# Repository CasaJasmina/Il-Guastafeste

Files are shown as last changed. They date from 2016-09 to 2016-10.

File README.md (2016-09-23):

# Il-Guastafeste
Il guastafeste repository 

Il Guastafeste is a Party/Sound Silencer System that interacts directly with your home’s audio stereo devices and lights. 
The system is able to detect the noise present in the house, if the sound is too noisy after 23 O’Clock, 
Il Guastafeste gives the user two chances to turn down the music volume and save the relationship with the neighbours. 
If not, il Guastafeste will shut down the music and dim down the lights, breaking the party.

Il Guastafeste will be exhibited at Maker Faire Home 2016 in Rome and will be a permanent home smart living object at 
Casa Jasmina in Turin.

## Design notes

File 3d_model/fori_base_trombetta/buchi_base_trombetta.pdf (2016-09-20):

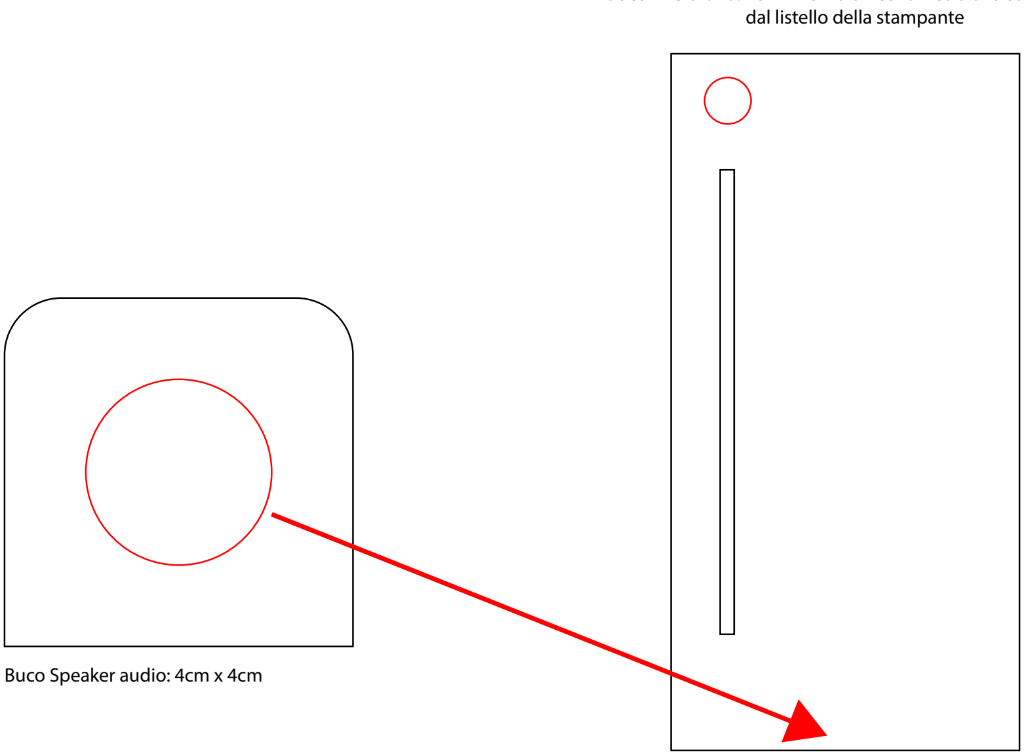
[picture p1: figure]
Buco Speaker audio: 4cm x 4cm; dal listello della stampante

Buco microfono: 1cm x 1cm a un centimetro di distanza

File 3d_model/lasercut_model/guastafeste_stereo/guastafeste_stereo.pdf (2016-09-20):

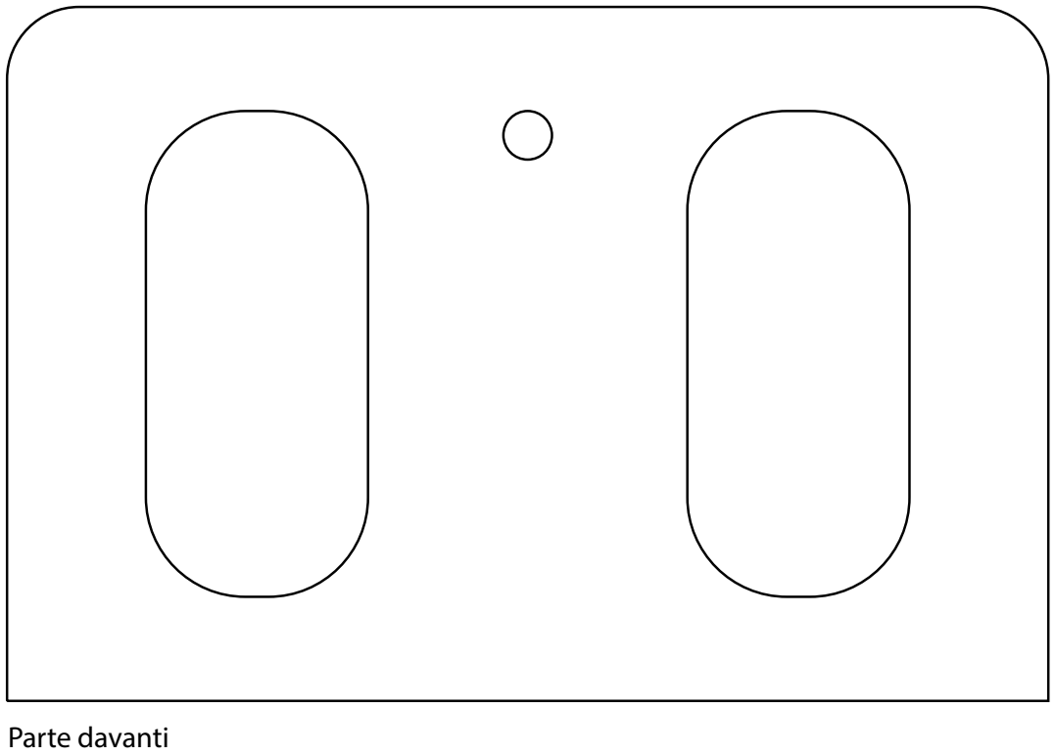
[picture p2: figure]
Parte davanti

Buchi speaker: 3,2 cm larghezza x 7 cm lunghezza buco potenziometro: 0,7 cm x 0,7 cm

Parte dietro
Buco 9V: 0,5 cm x 0,5 cm
Buco ipod/jack: 0,5 cm x 0,5 cm

Dimensioni totali: 15x10x5 (Profondità/lunghezza dei lati: 5 cm).

Purtroppo i lati non riesco a farli in Rhino per via dei bordi arrotondati superiori, bisognerebbe intagliarli con il pattern a zig zag che mi avevi fatto vedere
(in modo da essere essibili e quindi arrotondabili).

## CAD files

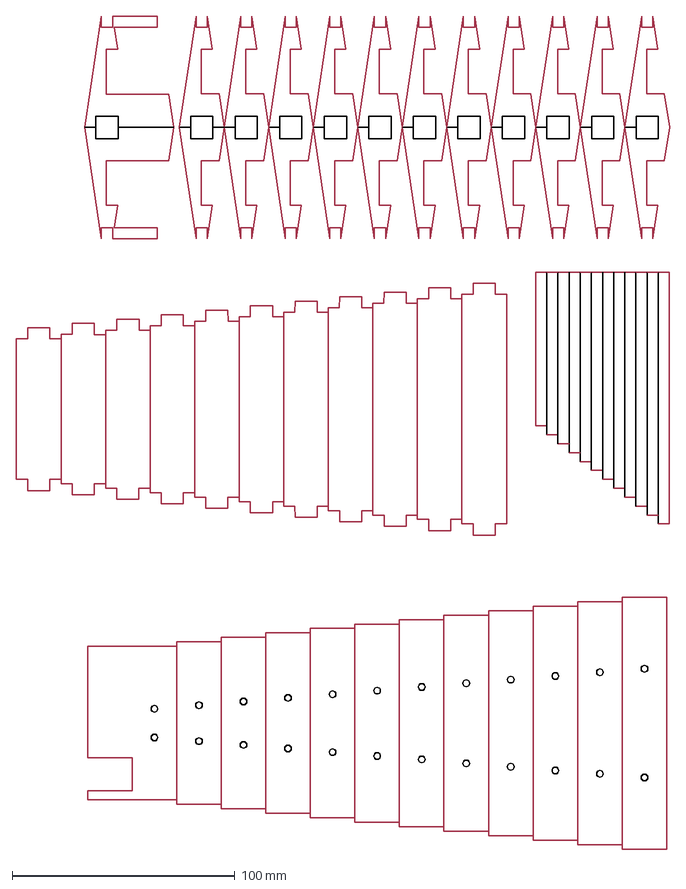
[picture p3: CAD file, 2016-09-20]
3d_model/lasercut_model/guastafeste_trombetta/gustafeste_trombetta_final_14_44.dxf
293.2 x 374.0 mm

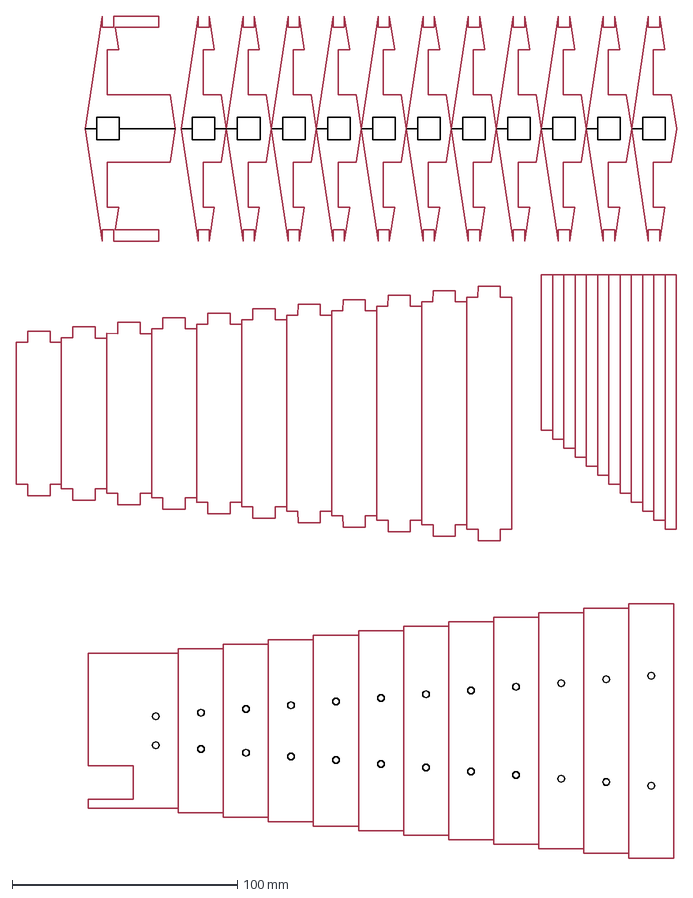
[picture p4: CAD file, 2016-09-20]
3d_model/lasercut_model/guastafeste_trombetta/gustafeste_trombetta_final_14_32.dxf
293.2 x 374.0 mm

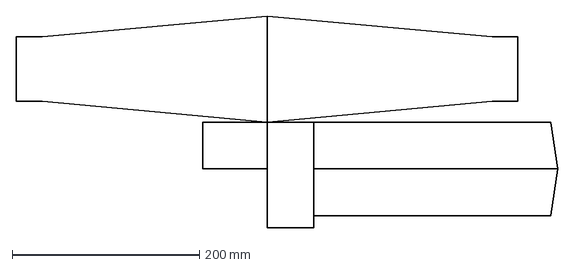
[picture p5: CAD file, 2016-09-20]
3d_model/lasercut_model/guastafeste_trombetta/guastafeste_lycra_15_02.dxf
577.5 x 226.0 mm

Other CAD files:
3d_model/3d_printing_model/luce_trombetta/base_luce.3dm
3d_model/3d_printing_model/parte_gialla_trombetta/YellowIvanSeal.3dm
3d_model/3d_printing_model/rocchetto_trombetta/rocchetto_servo_trombetta.3dm
3d_model/3d_printing_model/trace_il_guastafeste/trace_guastafeste.3dm
3d_model/lasercut_model/guastafeste_stereo/guastafeste_stereo_final.3dm
3d_model/lasercut_model/guastafeste_trombetta/ilguastafeste_lingua.3dm

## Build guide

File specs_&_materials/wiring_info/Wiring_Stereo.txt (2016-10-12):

Amplifier
VDD -> 5v
GND -> GND
L+ -> dac0
L- -> GND
G0 -> 5
G1 -> 4
SR -> 3
SL -> 2

Potentiometer
A -> A1
GND -> GND
5v -> 5v

Jack
right -> R+
left -> L+

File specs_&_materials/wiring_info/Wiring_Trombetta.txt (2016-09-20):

Amplifier
VDD -> 5v
GND -> GND
L+ -> dac0
L- -> GND
G0 -> 2
G1 -> 3

Micro-SD

3v -> VCC
GND -> GND
SCLK -> 9
DO -> 10
DI -> 8
CS -> 4

Microphone
DO -> A1
+ -> 5v
G -> GND

Thermal Printer
GND -> GND
RX -> 14
5v -> 5v

Servo
GND -> GND
5v -> 5v
D -> 5

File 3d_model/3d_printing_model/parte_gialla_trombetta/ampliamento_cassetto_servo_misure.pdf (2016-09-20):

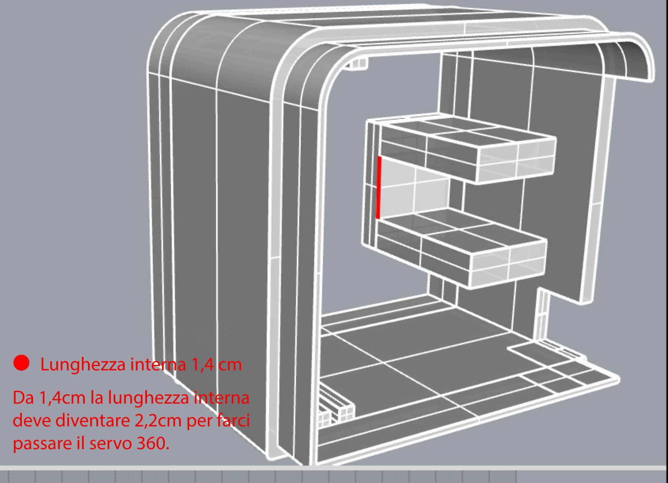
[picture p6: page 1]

䰀甀渀最栀攀稀稀愀椀渀琀攀爀渀愀㄀Ⰰ㐀挀洀
䐀愀㄀Ⰰ㐀挀洀氀愀氀甀渀最栀攀稀稀愀椀渀琀攀爀渀愀
搀攀瘀攀搀椀瘀攀渀琀愀爀攀㈀Ⰰ㈀挀洀瀀攀爀昀愀爀挀椀 瀀愀猀猀愀爀攀椀氀猀攀爀瘀漀㌀㘀　⸀

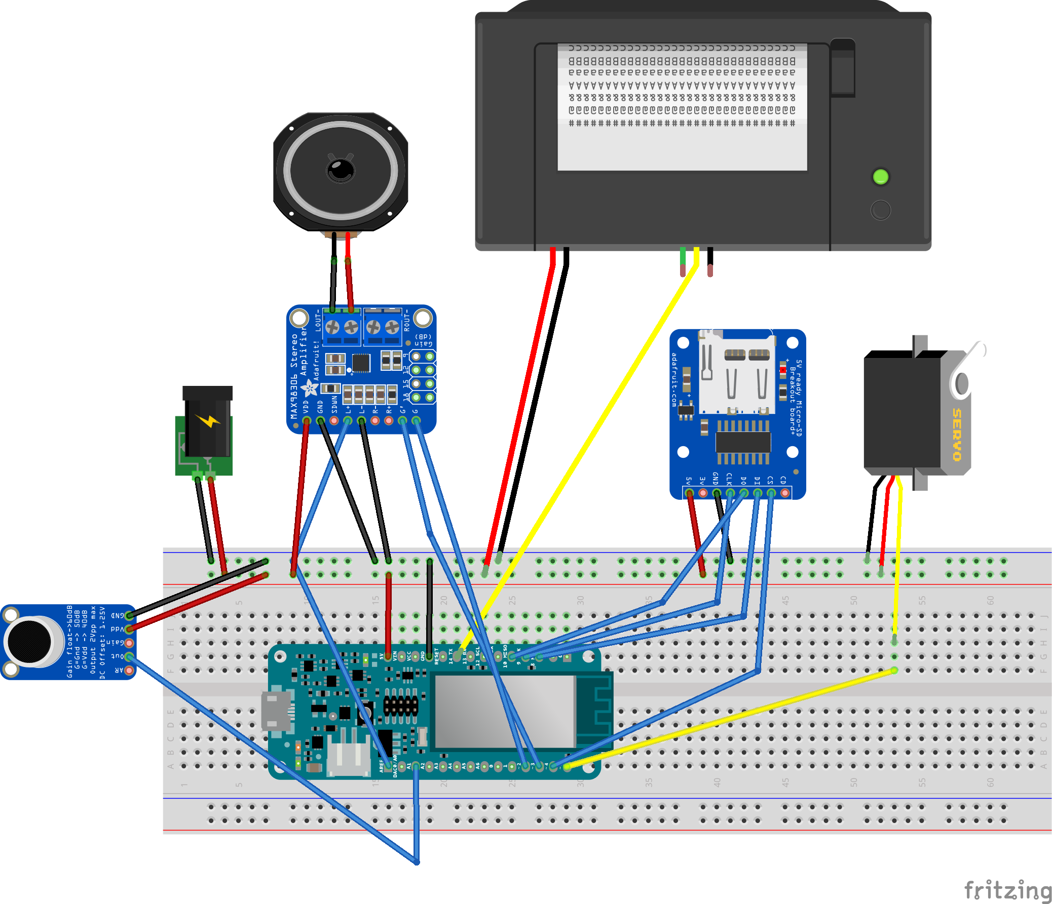
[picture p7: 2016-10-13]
specs_&_materials/wiring_info/fritzing/il_guastafeste_trombetta.png

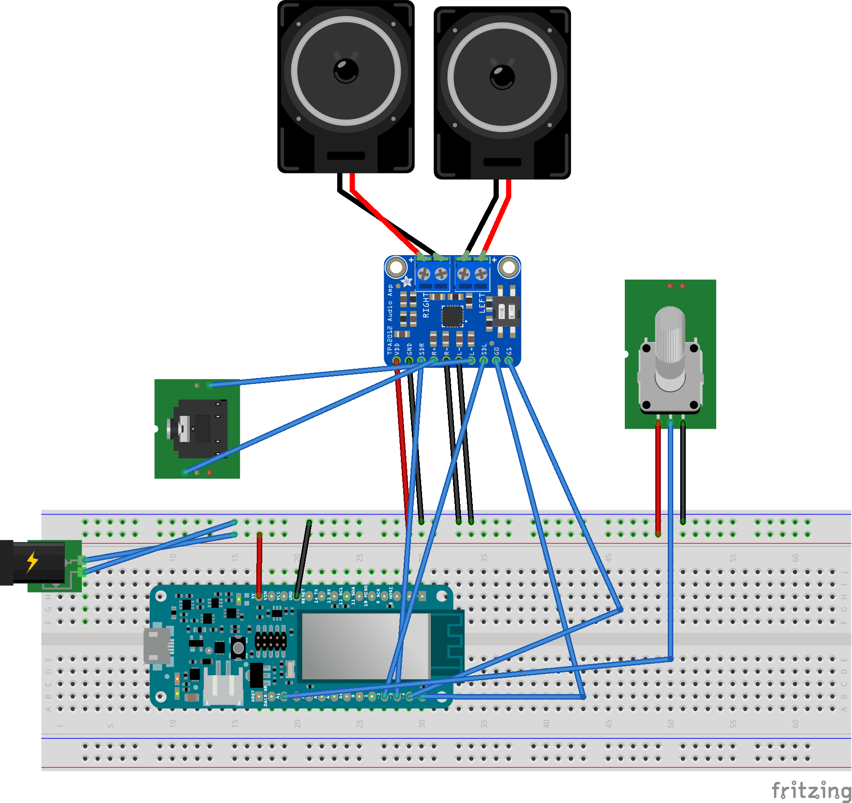
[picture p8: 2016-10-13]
specs_&_materials/wiring_info/fritzing/il_guastafeste_stereo.png

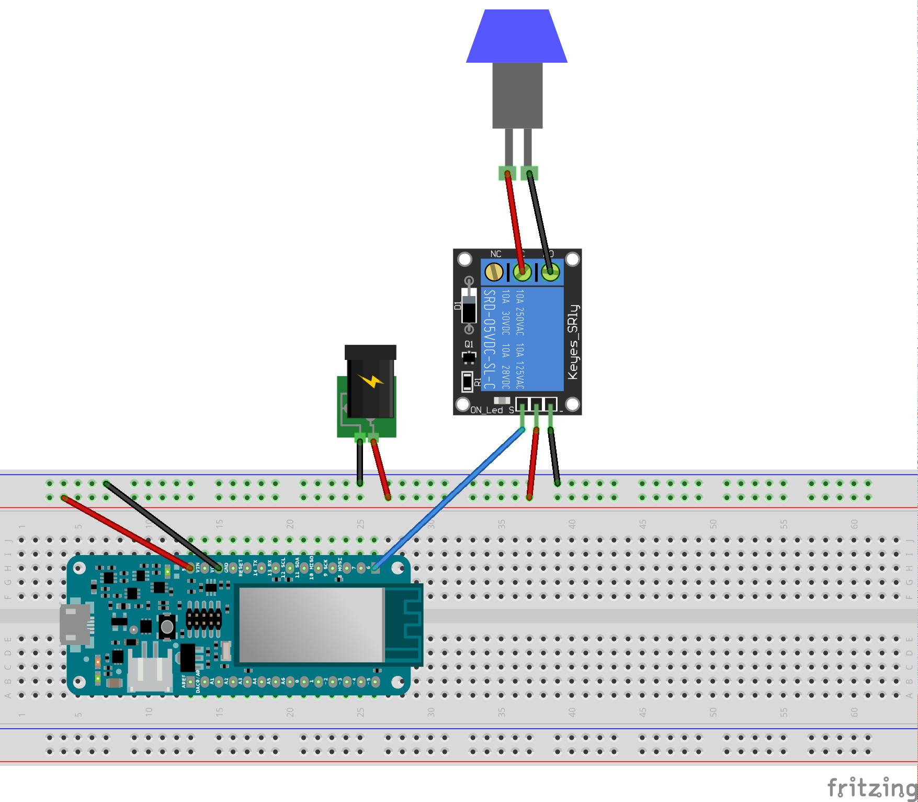
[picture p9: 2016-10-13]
specs_&_materials/wiring_info/fritzing/il_guastafeste_light.png

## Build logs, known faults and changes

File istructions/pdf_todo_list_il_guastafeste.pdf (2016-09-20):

## Todo List il Guastafeste

Design Stereo:

- Allo stereo manca ancora un case, che io farei in legno. Ho disegnato il case in Rhino e l’ho estruso, tuttavia non sono riuscito a fare le pareti dato che la parte superiore del Case è arrotondata e non so come si fa il pattern a zig-zag per rendere flessibile i bordi. Ti prego di dare una controllata al file prima di esportarlo in .dxf . Il File lo trovi qui:

3d_model -> lasercut_model -> guastafeste_stereo

Nel link troverai un pdf con le lunghezze e larghezza, cosi come il file .3dm fatto da me.

Design Trombetta:

- Purtroppo nella trombetta dobbiamo ristampare la parte gialla che aveva fatto Tommaso, dato che ora utilizzo un Servo 360 (è più grande del Servo normale). Tuttavia, l’unica cosa da cambiare è solo la grandezza del “cassettino” del servo. Anche qui, tutte le info (Grandezze e pezzo da ridimensionare le trovi nel seguente link:

3d_model -> 3d_printing_model -> parte_gialla_trombetta

- Per il Servo 360, ho progettato anche un rocchetto come testa del motore del servo, che servirà a far arrotolare e bloccare (nei due buchi) il filo di nylon che gestisce il “naso” della trombetta. Se dovesse essere troppo dispendioso stampare il pezzo, puoi incollare il rocchetto di plastica che ti ho inviato sulla parte plastica alla testa del motore, facendo attenzione a tenere in alto la parte con il buco (servirà a tenere fermi le due estremità del filo di nylon).

3d_model -> 3d_printing_model -> rocchetto_trombetta
(le grandezze le trovi insieme al model nel file .3dm)

I due buchi servono per l’appunto a bloccare il filo, con un bel nodino, una volta che la parte superiore è srotolata del tutto.

- Nella parte bianca, dove verranno installati lo speaker, la Thermal Printer e il microfono, mancano ancora i buchi per lo Speaker e per il microfono. Tommaso voleva farli con il Dremel. Nel link sottostante trovi le grandezze e la posizione in cui dovranno essere fatti i buchi.

3d_model -> fori_base_trombetta

Design Luce:

- Per la luce bisogna ancora fare la parte di decoro, onestamente non ho fatto praticamente nulla a riguardo, dato che la luce, il relay e l’arduino annesso l’ho lasciato a Torino. Qui ti puoi sbizzarrire te, per me è uguale quale tipo design abbia la lampada, fai che ti riesce più veloce. Purtroppo non ho alcuna misura, sia del bulbo che della parte superiore della lampada

Programmazione Servo Trombetta:

Una volta collegato il Servo alla parte superiore della Trombetta (Arrotolando il Nylon nel rocchetto e fissandolo fuori facendolo passare dai buchi), potrai testare la velocità e forza del Servo. Nel caso in cui il Servo non fosse in grado di alzare tutta la parte, puoi sempre modificare il codice, aumentando la velocità.

Le linee di codice da modificare sono le seguenti:

Linea 176 -> servoMotor(true,500,20);
Linea 230 -> servoMotor(true,500,20);
Linea 253 -> servoMotor(false,500,20);
Linea 285 -> servoMotor(true,500,20);
Linea 316 -> servoMotor(false,1000,20);
Linea 339 -> servoMotor(false,1500,20);

In tutte queste linee dovrai sostituire l’ultimo parametro della funzione servoMotor (ovvero il 20), con il numero 40 o 60, in base alla quantità di velocità che necessita il Servo.

Il file lo trovi qui:

final_sketches -> _2016_09_08_ilguastafeste_trombetta -> _2016_09_08_ilguastafeste_trombetta.ino

Altro:

Per la Maker Faire avrei bisogno anche di un rullino di carta nuovo per la Thermal Printer e di una batteria LiPo Battery o caricatore Usb (con la presa per la corrente elettrica) per l’arduino che gestisce la luce.

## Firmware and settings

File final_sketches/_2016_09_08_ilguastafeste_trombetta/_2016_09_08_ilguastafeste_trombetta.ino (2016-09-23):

/*
 *  8 September 2016
 *  Il Guastafeste - Trombetta
 *  Ivan Iovine
 *  
 *  Casa Jasmina / Maker Faire Rome
 *
 */

 
#include <Servo.h>
//Include Libraries for WLAN and MQTT Communication
#include <WiFi101.h>
#include <WiFiUdp.h>
#include <ArduinoCloud.h>

// Library for Thermal Printer
#include "Adafruit_Thermal.h"

// Libraries for Audio File
#include <SPI.h>
#include <SD.h>
#include <AudioZero.h>

//Libraries for Hours - RTC
#include <RTCZero.h>

// build a wifi object
WiFiSSLClient sslClient;

// build a RTCZero object
RTCZero rtc;

// build a UDP Connection object
WiFiUDP Udp;

// build a new object "ilguastafestetrombetta"
ArduinoCloudThing ilguastafestetrombetta;

// Servo object
Servo servoguastafeste;  // create servo object to control a servo


Adafruit_Thermal printer(&Serial1);
#define TX_PIN 1 // Arduino transmit  PIN 14
#define RX_PIN 0 // Arduino receive

// Variables for WLAN Communication
char *ssid = "";
char *pass = "";

// Arduino Cloud settings and credentials
const char userName[]   = "dummknopf";
const char thingName[] = "ilguastafestetrombetta";
const char thingId[]   = "c8f20740-561f-4991-ba06-c0cc8ed349b1";
const char thingPsw[]  = "687e8869-815f-4d25-965d-b166b6a9b0da";

// UDP setup
unsigned int localPort = 2390;      // local port to listen for UDP packets
IPAddress timeServer(129, 6, 15, 28); // time.nist.gov NTP server
const int NTP_PACKET_SIZE = 48; // NTP time stamp is in the first 48 bytes of the message
byte packetBuffer[ NTP_PACKET_SIZE]; //buffer to hold incoming and outgoing packets
const int GMT = 2; //change this to adapt it to your time zone   hours*minutes*seconds

// Set Il Guastafeste Alarm
int hours = 13;
int minutes = 0;
int seconds = 0;
boolean after = false; // Check if time is after 23 hours


// Messages to Print
boolean message = false; // Check if it's time to print the message
String stepOne = "It's too Loud, please be Quiet!";
String stepTwo = "This is the last Warning!";
String stepThree = "The Party is over, Good Night!"; 

// twelve servo objects can be created on most boards
int pos = 90;    // variable to store the servo position
boolean stop_servo = true;

// millis variables for average noise value
unsigned long previousMillis = 0; 
unsigned long currentMillis;
const long interval = 30000;

// Variables for the Microphone
float totValue;
float loudValue;
unsigned int sample;
int peakRaw;
int countLoud = 0;



void setup() {
  
  Serial.begin (9600); 

  // attempt to connect to WiFi network:
  //Serial.print("Attempting to connect to WPA SSID: ");
  //Serial.println(ssid);
  
  // Check if the MKR1000 is connected on WIFI
  if(WiFi.begin(ssid, pass) != WL_CONNECTED) {
    // unsuccessful, retry in 4 seconds
    Serial.print("failed ... ");
    delay(4000);
    Serial.print("retrying ... ");
  }
  else
  {
    //
  }
    //Begin Printer Serial
    Serial1.begin(9600);
    
    //Begin Printer Library
    printer.begin(250);

    //Begin Time the libraries and Functions
    rtc.begin();
    GetCurrentTime();

    // Begin MQTT Communication
    ilguastafestetrombetta.begin(thingName, userName, thingId, thingPsw, sslClient);
    ilguastafestetrombetta.enableDebug();
    
    // define the properties
    ilguastafestetrombetta.addProperty("ilguastafestemaster", CHARSTRING, RW);
    ilguastafestetrombetta.addExternalProperty("ilguastafestestereo","ilguastafestestereoslave",CHARSTRING);
    
     if(!SD.begin(4)) {
      Serial.println("failed!");
     }
     else
     {
      Serial.println("Valid SD Card");
     }

       // Init Servo
    //servoguastafeste.attach(5);  // attaches the servo on pin 5 to the servo object


  
}

void loop() {
  
  currentMillis = millis();
  peakRaw = peak();
    
  ilguastafestetrombetta.poll();
  
    switch (countLoud) {
      case 0:
        
      totValue += peakRaw;
      if (currentMillis - previousMillis >= interval) 
      {
        previousMillis = currentMillis;
        Serial.println(totValue);
        Serial.println(interval);
        loudValue = (interval/totValue)*1000;
        Serial.println(loudValue);
    
        if(loudValue <= 500 && loudValue >= 1)
        {
            // Turn Down Stereo Volume
            ilguastafestetrombetta.writeProperty("ilguastafestemaster", "loud");
            
            // Change here the proprietes to manipulate the servo
            stop_servo = false; 
            if(stop_servo == false)
            {
              servoMotor(true,500,20);
              stop_servo = true;
            }
    
            message = true;
            
            if(message == true)
            {
              // Print the message
              printMessage(stepOne);
              Serial.println("Print Message!");
              message = false;
            }

            countLoud = 1;     
        }
        else
        {
          // Change here the proprietes to manipulate the servo
          stop_servo = false; 
          if(stop_servo == false)
          {
            servoMotor(false,500,0);
            stop_servo = true;
          }
          restart();
          Serial.println("COUNTLOUD 0");
       
        }
          totValue = 0; 
      }
      
      break;
      case 1:

      totValue += peakRaw;
      if (currentMillis - previousMillis >= interval) 
      {
        previousMillis = currentMillis;
        Serial.println(totValue);
        Serial.println(interval);
        loudValue = (interval/totValue)*1000;
        Serial.println(loudValue);
        
        if(loudValue <= 500 && loudValue >= 1)
        {
        
            // Turn Down Stereo Volume
             ilguastafestetrombetta.writeProperty("ilguastafestemaster", "tooloud");
             
             // Change here the proprietes to manipulate the servo
            stop_servo = false; 
            if(stop_servo == false)
            {
              servoMotor(true,500,20);
              stop_servo = true;
            }
    
             message = true;
            
            if(message == true)
            {
               // Print the message
               printMessage(stepTwo);
               Serial.println("Print Message!");
               message = false;
            } 

            countLoud = 2;
        }
        else
        {
          
          // Change here the proprietes to manipulate the servo
          stop_servo = false; 
          if(stop_servo == false)
          {
            servoMotor(false,500,20);
            stop_servo = true;
          }
          restart();
          Serial.println("COUNTLOUD 0");
  
        }
          totValue = 0;
      }
           
      break;
      case 2:

      totValue += peakRaw;
      if (currentMillis - previousMillis >= interval) 
      {
        previousMillis = currentMillis;
        Serial.println(totValue);
        Serial.println(interval);
        loudValue = (interval/totValue)*1000;
        Serial.println(loudValue);
        
        if(loudValue <= 500 && loudValue >= 1)
        {

            // Turn Out Lights and Stereo
            ilguastafestetrombetta.writeProperty("ilguastafestemaster", "partyisover");

            stop_servo = false; 
            if(stop_servo == false)
            {
              // Change here the proprietes to manipulate the servo
              servoMotor(true,500,20);
              stop_servo = true;
            }
                      
            message = true;
            
            if(message == true)
            {
              // Print the message
              printMessage(stepThree);
              Serial.println("Print Message!");
              message = false;
            }
            delay(2000);
            //Set Volume Speaker
            digitalWrite(1, HIGH);
            digitalWrite(2, LOW);
            digitalWrite(3, LOW);
            //Play the final sound
            finalAudio();
    
            // Restart the Sketch!
            countLoud = 3;
        }
        else
        {
          
          // Change here the proprietes to manipulate the servo
          stop_servo = false; 
          if(stop_servo == false)
          {
            servoMotor(false,1000,20);
            stop_servo = true;
          }
          restart();
          Serial.println("COUNTLOUD 0");
          
        }
          
          totValue = 0; 
        
        }
        
      break;
      case 3:

      totValue += peakRaw;
      if (currentMillis - previousMillis >= interval) 
      {
              delay(26000);
              // Change here the proprietes to manipulate the servo
              stop_servo = false; 
              if(stop_servo == false)
              {
                servoMotor(false,1500,20);
                stop_servo = true;
              }
              restart();
      }
      
      break;
      default:
        // Nothing happens here
      break;
    }
  }


//Printer Function
void printMessage(String stepMessage)
{
  
  printer.setSize('S');
  printer.justify('C');
  printer.println(stepMessage);
  printer.feed(5);
}

// Audio Speaker Function
void finalAudio()
{
   AudioZero.begin(44100);
   File audioFile = SD.open("tt.wav"); // open wave file from sdcard
    if (!audioFile) {
      Serial.println("error opening tt.wav");
    }
    AudioZero.play(audioFile);
    AudioZero.end();
}

// Take Raw Data every 50 ms from Microphone
int peak()
{
    unsigned long startMillis= millis();  // Start of sample window
    int peakToPeak = 0;   // peak-to-peak level
     
    unsigned int signalMax = 0;
    unsigned int signalMin = 1024;

     
       // collect data for 50 mS
       while (millis() - startMillis < 50)
       {
          sample = analogRead(A1);
          //Serial.println(sample);
          if (sample < 1024)  // toss out spurious readings
          {
             if (sample > signalMax)
             {
                signalMax = sample;  // save just the max levels
             }
             else if (sample < signalMin)
             {
                signalMin = sample;  // save just the min levels
             }
          }
       }
       peakToPeak = signalMax - signalMin;  // max - min = peak-peak amplitude
       return peakToPeak;
       Serial.println(peakToPeak);
       delay(500);
}

void restart()
{

     //Restart State
     ilguastafestetrombetta.writeProperty("ilguastafestemaster", "restart");
     delay(2000);
     countLoud = 0;
     totValue = 0; 
     Serial.println("Reset!");
     

}

void servoMotor(boolean forward,int m,int vel)
{
  if(forward == true)
  {
    servoguastafeste.attach(5);
    Serial.println("Run Run Run!");
    servoguastafeste.write(pos - vel);
    delay(m);
    servoguastafeste.detach();
    
  }
  else
  {
    servoguastafeste.attach(5);
    Serial.println("Run Run Run!");
    servoguastafeste.write(pos + vel);
    delay(m);
    servoguastafeste.detach();   
  }

}

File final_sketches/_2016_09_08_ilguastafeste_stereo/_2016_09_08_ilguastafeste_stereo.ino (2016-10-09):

/*
 *  8 September 2016
 *  Il Guastafeste - Stereo
 *  Ivan Iovine
 *  
 *  Call for Residency - Casa Jasmina / Maker Faire Rome 
 */
#include <WiFi101.h>
#include <ArduinoCloud.h>

// variables for WLAN Communication
char *ssid = "";
char *pass = "";

// arduino cloud settings and credentials
const char userName[]   = "dummknopf";
const char thingName[] = "ilguastafestestereo";
const char thingId[]   = "4f9ccd39-013d-4619-a526-6fa5545b50d7";
const char thingPsw[]  = "9b4510e3-31f3-4083-9aa7-d69bfc8b72f3";

// variable to set the gain
int pinGain0 = 5;    
int pinGain1 = 4; 

int shutRight = 3;    // variable to shut down the right speaker
int shutLeft = 2;    // variable to shut down the left speaker

int potVal;         // variable to read the potentiometer

//Check Variables for time and set state
int step1 = 0;
int step2 = 0;
int step3 = 0;
int countState = 0;

// build a new object for the wifi client
WiFiSSLClient sslClient;


// build a new object "ilguastafestestereo"
ArduinoCloudThing ilguastafestestereo;

void setup() {
  
  Serial.begin(9600);

  while (WiFi.begin(ssid, pass) != WL_CONNECTED) {
    // unsuccessful, retry in 4 seconds
    Serial.print("failed ... ");
    delay(4000);
    Serial.print("retrying ... ");
  }

  ilguastafestestereo.begin(thingName, userName, thingId, thingPsw, sslClient);
  ilguastafestestereo.enableDebug();
   // define the properties
  ilguastafestestereo.addProperty("ilguastafestestereoslave", CHARSTRING, RW);
  ilguastafestestereo.addExternalProperty("ilguastafestetrombetta","ilguastafestemaster",CHARSTRING);
}

void loop() {

  potVal = map(analogRead(A1),0,1023,1024,0);
  ilguastafestestereo.poll();
  countState = setStates();
  
  switch(countState){
    case 0:

     step1 = 0;
     step2 = 0;
     digitalWrite(shutRight, HIGH);
     digitalWrite(shutLeft, HIGH);
     digitalWrite(pinGain0, LOW);
     digitalWrite(pinGain1, LOW);
     setVolume(potVal);
     Serial.println("Let's Start!");
     
    break;
    case 1:
    
     step1++;
     Serial.println(step1);
     if(step1 < 15000)
     {  
        digitalWrite(shutRight, HIGH);
        digitalWrite(shutLeft, HIGH);
        analogWrite(pinGain0, HIGH);
        analogWrite(pinGain1, HIGH);
        Serial.println("Step 1");
     }
     else
     {
        setVolume(potVal);
     }
   break;
   case 2:
   
     step2++;
     Serial.println(step2);
     if(step2 < 15000)
     {
        digitalWrite(shutRight, HIGH);
        digitalWrite(shutLeft, HIGH);
        analogWrite(pinGain0, HIGH);
        analogWrite(pinGain1, HIGH);
        Serial.println("Step 2");
     }
     else
     {
        setVolume(potVal);
     }
     
   break;
   case 3:

        analogWrite(shutRight, HIGH);
        analogWrite(shutLeft, HIGH);
        Serial.println("Step 3");
        delay(2000);
        step1 = 0;
        step2 = 0;
        
   break;
   default:
   // Nothing to do here
   break;
  }
  
  Serial.println(countState);
 
}


int setStates()
{

   //Serial.println(ilguastafestestereo.readProperty("ilguastafestetrombetta","ilguastafestemaster"));
   if(ilguastafestestereo.readProperty("ilguastafestetrombetta","ilguastafestemaster") == "loud")
   {
       return 1;
   }
   else if(ilguastafestestereo.readProperty("ilguastafestetrombetta","ilguastafestemaster") == "tooloud")
   {
       return 2;
   } 
   else if(ilguastafestestereo.readProperty("ilguastafestetrombetta","ilguastafestemaster") == "partyisover")
   {
        return 3;
   }
   else if(ilguastafestestereo.readProperty("ilguastafestetrombetta","ilguastafestemaster") == "restart")
   {
        return 0;
   }
   else
   {
        return 0;
   }

}


void setVolume(int p)
{
   Serial.println(p);
   if(p >= 0 && p < 2)
   {
     Serial.println("Shut Down");
     //Shut Down
     digitalWrite(pinGain0, LOW);
     digitalWrite(pinGain1, LOW);  
     analogWrite(shutRight, HIGH);
     analogWrite(shutLeft, HIGH);
   }
   else if(p > 2 && p < 350)
   {
       Serial.println("MID-LOW Volume");
       //MID-LOW Volume
       digitalWrite(pinGain0, LOW);
       digitalWrite(pinGain1, LOW);
       analogWrite(shutRight, LOW);
       digitalWrite(shutLeft, HIGH);

    
   }
   else if(p > 350 && p < 700)
   {
       Serial.println("MID-HIGH Volume");
       //MID-HIGH Volume
       digitalWrite(pinGain0, LOW);
       digitalWrite(pinGain1, LOW);
       digitalWrite(shutRight, HIGH);
       analogWrite(shutLeft, HIGH);
    
   }
   else if (p > 700 && p < 1024)
   {
       Serial.println("HIGH Volume");
       //HIGH Volume
       digitalWrite(pinGain0, LOW);
       digitalWrite(pinGain1, LOW);
       digitalWrite(shutRight, HIGH);
       digitalWrite(shutLeft, HIGH);
   }
   else
   {
    // Nothing to do here
   }
  
}

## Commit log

2016-09-20 Struttura generale della repository
    Files riguardanti il progetto il Guastafeste. Ivan Iovine
    [YellowIvanSeal.3dm, guastafeste_lycra_15_02.dxf, guastafeste_stereo.3dm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]
2016-09-30 added trace for desc in .ai format
    [trace_guastafeste.3dm]
2016-10-03 final file to print stereo
    [guastafeste_stereo_final.3dm]
2016-10-09 add text for Wiring Relay Light
2016-10-09 added light base 3d model for 3d printing
    [base_luce.3dm]
2016-10-12 new stereo wiring
2016-10-13 fritzing schemas added
    [il_guastafeste_light.fzz, il_guastafeste_stereo.fzz, il_guastafeste_trombetta.fzz]
